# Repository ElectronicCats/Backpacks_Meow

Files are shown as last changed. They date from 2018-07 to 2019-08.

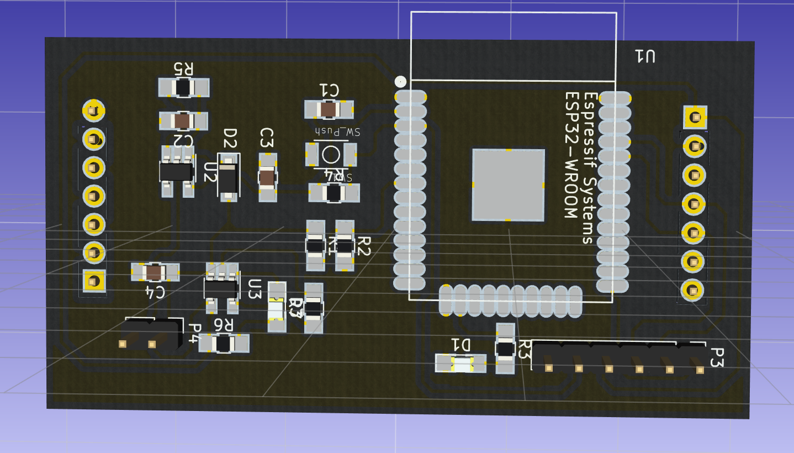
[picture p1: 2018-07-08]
BLE_WIFI_HID/BLE_WIFI_HID.png

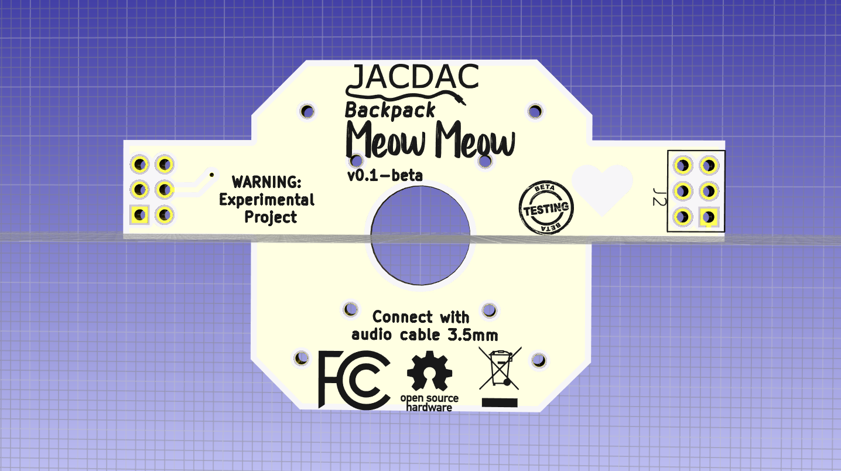
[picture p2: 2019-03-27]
jacdac/beta-v0.1_back.png

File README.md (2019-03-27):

# Backpacks Meow Meow

> WARNING: The Backpacks for Meow Meow are very much still under development and subject to change. If you would like to contribute features and ideas, please send pullrequest to this github repository or file an issue.

## Backpacks

### JACDAC

The JACDAC Connect system uses the JACDAC (Joint Asynchronous Communications) protocol, a single cable transmission protocol for the plug and play of accessories for microcontrollers.

We have adapted this technology to unlock the following benefits:

- No welding between JACDAC breakouts
- Connectors with 3.5mm audio plug to avoid connection errors.
- Ability to create a chain in series where you can connect multiple devices.

More [info about JACDAC](https://jacdac.org/)

### BLE HID
Add wireless connection functionality to your Meow Meow thanks to bluetooth 4.0

## LICENSE

Hardware released under an CERN Open Hardware Licence v1.2. See the LICENSE_HARDWARE file for more information.

Designed by Electronic Cats.

Electronic Cats is a registered trademark, please do not use if you sell these PCBs.

Electronic Cats invests time and resources providing this open source design, please support Electronic Cats and open-source hardware by purchasing products from Electronic Cats!

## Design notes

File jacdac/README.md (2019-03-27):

# Make JACDAC System with Meow Meow Backpack

> **Status Tutorial: Experimental**

This tutorial shows you how to build your own MakeCode JACDAC using an [Meow Meow](https://www.electroniccats.com) as the controller sensors device.

## Parts needed

Before you begin, you're going to need a few parts which are shown in the diagram below.

Also, here's a list of where you can buy the parts and a brief description of what each part does too.

* 2 x [Meow Meow](https://www.electroniccats.com) - This will run the code for the project you will be creating.
* 2 x [Meow Meow Backpack JACDAC](https://) - This will connect the Meow Meow to other Meow Meow, using our JACDAC protocol. 

# ALERT:

> **Always** only one device Meow Meow at a time must be connected to the computer.
> 
> Before starting, you must disconnect all the Meow Meows from the USB cable or any other external power supply

## Assembling your MakeCode

The diagram shown at the beginning is what we're going to build as we connect everything together.

### Step 1: Open Maker MakeCode
Open your browser and go to [https://maker.makecode.com/](https://maker.makecode.com/), open "New Project" and select the board Meow Meow, select in mode Javascript your editor code.

### Step 2: Connecting the 3.5mm Audio Jack Connector to the "Meow Meow Host" to the others "Meow Meow Peripheral"

Using a standard audio cable, connect your Meow Meow Host to the Meow Meows Peripheral, as shown in the picture below.

**[!Need an Meow Meow board connection image to go here!](#)**

It does not matter in which connector you place the cable and it is not necessary to make any other connection.

### Step 3: Load an example that uses JACDAC onto the Meow Meow Host 

As mentioned earlier, we're going to be using the protocol called JACDAC to connect the Meow Meow with others Meow Meow to a controller.

Load this code from MakeCode onto your Meow Meow Host:

```typescript-ignore
jacdac.keyboardService.start()
```
 
For more information on the JACDAC protocol, check out this link: [https://jacdac.org/](https://jacdac.org/
)

### Step 4: Load controller code onto Meow Meow Peripheral that uses JACDAC

The Meow Meows Peripheral serves as our controllers for the Meow Meow Host. 

Load this code from MakeCode (beta) onto your Meow Meows Peripherals to use it as a keyboard:

```typescript-ignore
enum JacDacMessage {
    message1 = 49434,
    start = 56380
}
input.touchA0.onEvent(ButtonEvent.Down, function () {
    jacdac.keyboardClient.mediaKey(JDKeyboardMediaKey.Mute, JDKeyboardKeyEvent.Press)
})
input.touchA5.onEvent(ButtonEvent.Down, function () {
    jacdac.keyboardClient.key("a", JDKeyboardKeyEvent.Press)
})
input.touchA1.onEvent(ButtonEvent.Down, function () {
    jacdac.keyboardClient.mediaKey(JDKeyboardMediaKey.VolumeUp, JDKeyboardKeyEvent.Press)
})
input.touchA2.onEvent(ButtonEvent.Down, function () {
    jacdac.keyboardClient.mediaKey(JDKeyboardMediaKey.VolumeDown, JDKeyboardKeyEvent.Press)
})
input.touchA3.onEvent(ButtonEvent.Down, function () {
    jacdac.keyboardClient.key("b", JDKeyboardKeyEvent.Press)
})
input.touchA4.onEvent(ButtonEvent.Down, function () {
    jacdac.keyboardClient.key("b", JDKeyboardKeyEvent.Press)
})
```

### Step 5: Connect the Meow Meow Host to PC

> Remember **always** only one device Meow Meow at a time must be connected to the computer.

After everything is plugged in, turn on the Meow Meow Host and start playing!!

Enjoy!

## TODO

* Add pictures
* Add gifs of example game running

## Resources

### Developer

* [Makecode Maker (beta)](https://maker.makecode.com/beta)
* [JACDAC](https://jacdac.org/)
* [ElectronicCats](https://www.electroniccats.com)

### Components

* [Meow Meow](https://www.electroniccats.com)
* [Meow Meow Backpack JACDAC](https://www.adafruit.com/product/2791/)

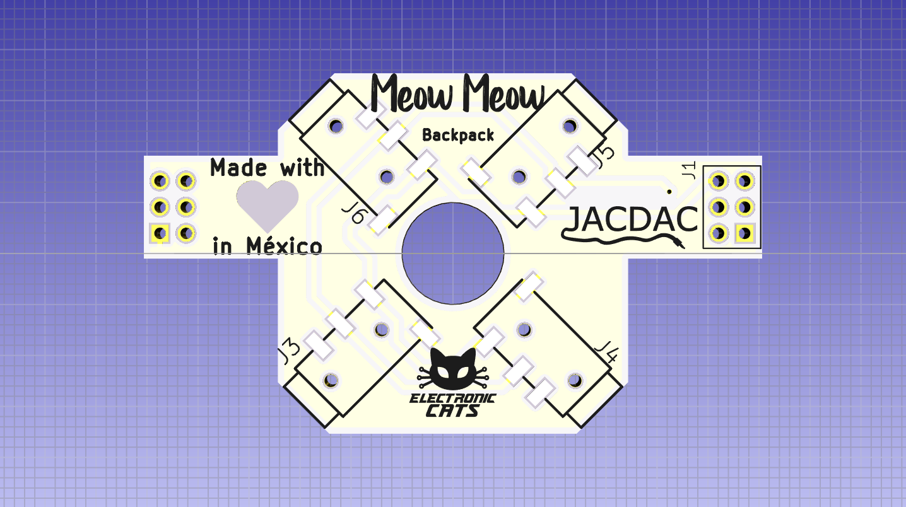
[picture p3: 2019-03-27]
jacdac/beta-v0.1_front.png

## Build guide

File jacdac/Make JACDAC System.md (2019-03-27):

# Make JACDAC System

This tutorial shows you how to build your own MakeCode JACDAC using an [Meow Meow](https://www.electroniccats.com), and the [Bast](https://www.electroniccats.com) as the controller sensors device.

## Parts needed

Before you begin, you're going to need a few parts which are shown in the diagram below.

Also, here's a list of where you can buy the parts and a brief description of what each part does too.

* [Meow Meow](https://www.electroniccats.com) - This will run the code for the game you will be creating.
* [Bast](https://www.electroniccats.com) - This act as your sensor device.
* [3.5mm Stereo Audio Jack Connector](https://www.adafruit.com/product/2791/) - This will connect the Meow Meow to the Bast, using our JACDAC protocol. 

## Assembling your MakeCode

The diagram shown at the beginning is what we're going to build as we connect everything together.

### Step 1: Connecting the 3.5mm Audio Jack Connector to the Meow Meow #step-1

Follow the diagram above to connect the audio jack.  For reference, this small chart shows the mapping for a typical 3.5mm Stero audio jack connector/pins to the protocol we will be using later (JACDAC). 

| 3.5mm Connector | JACDAC Protocol|
| --- | --- |
| Tip (or Left) | Connect to power source (if you want to draw power) |
| Ring (or Right) | Connect to data or tx line |
| Sleeve (or Ground) | Connect to a ground pin|
<br/>

Connecting the audio jack simply requires connecting the ring pin of the audio connector to the **TX** pin of the Meow Meow and connecting the sleeve pin of the audio connector to the ground (**G**) pin of the Meow Meow.

### Step 2: Connecting the 3.5mm Audio Jack Connector to the Cat hairs ball

Follow the diagram above for reference. Similar to [Step 1](#step-1), connect the ring pin of the audio connector to the **TX** pin of the cat hairs ball and connecting the sleeve pin of the audio connector to the **GND** pin of the Bast.

### Step 3: Load an example that uses JACDAC onto the Meow Meow

As mentioned earlier, we're going to be using the protocol called JACDAC to connect the Meow Meow with the screen to a controller. We do this because the Meow Meow contains the logic for the game, except it doesn't have enough pins for us to map buttons to an arcade controller. JACDAC lets us hook up different devices using audio connectors/cables, which is why we'll use the Basr as our controller.

Load this code from MakeCode onto your Meoe Meow:

```typescript-ignore
// code here or maybe a link???
// ...
```

>-- OR --
  
Load this code onto your Meow Meow:

```typescript-ignore
// code here or maybe a link???
// ...
```
 
For more information on the JACDAC protocol, check out this link: https://jacdac.org/

### Step 4: Load controller code onto the cat hairs ball that uses JACDAC

The cat hairs ball serves as our controller for the games we've already loaded onto the Meow Meow. 

Load this code from MakeCode (beta) onto your Bast to use it as a controller:

```typescript-ignore
// Bast controller code here or maybe a link???
// ...
```

### Step 5: Connect the the Meow Meow to the Bast

Using a standard audio cable, connect your Meow Meow to the Bast, as shown in the picture below.

**[!Need an Meow Meow board connection image to go here!](#)**

### Step 6: Enjoy!

After everything is plugged in, turn on both the Meow Meow and the Bast and start playing!!

## Todos

* Add Meow Meow code example link with JacDac
* Add Bast code example link with JacDac
* Add pictures
* Add gifs of example game running

## Resources

### Developer

* [Makecode Arcade (beta)](https://arcade.makecode.com/beta)
* [Makecode Maker (beta)](https://maker.makecode.com/beta)
* [JACDAC](https://jacdac.org/)
* [Adafruit](https://www.adafruit.com)

### Components

* [Meow Meow](https://www.electroniccats.com)
* [Bast](https://www.electroniccats.com)
* [3.5mm Stereo Audio Jack Connector](https://www.adafruit.com/product/2791/)

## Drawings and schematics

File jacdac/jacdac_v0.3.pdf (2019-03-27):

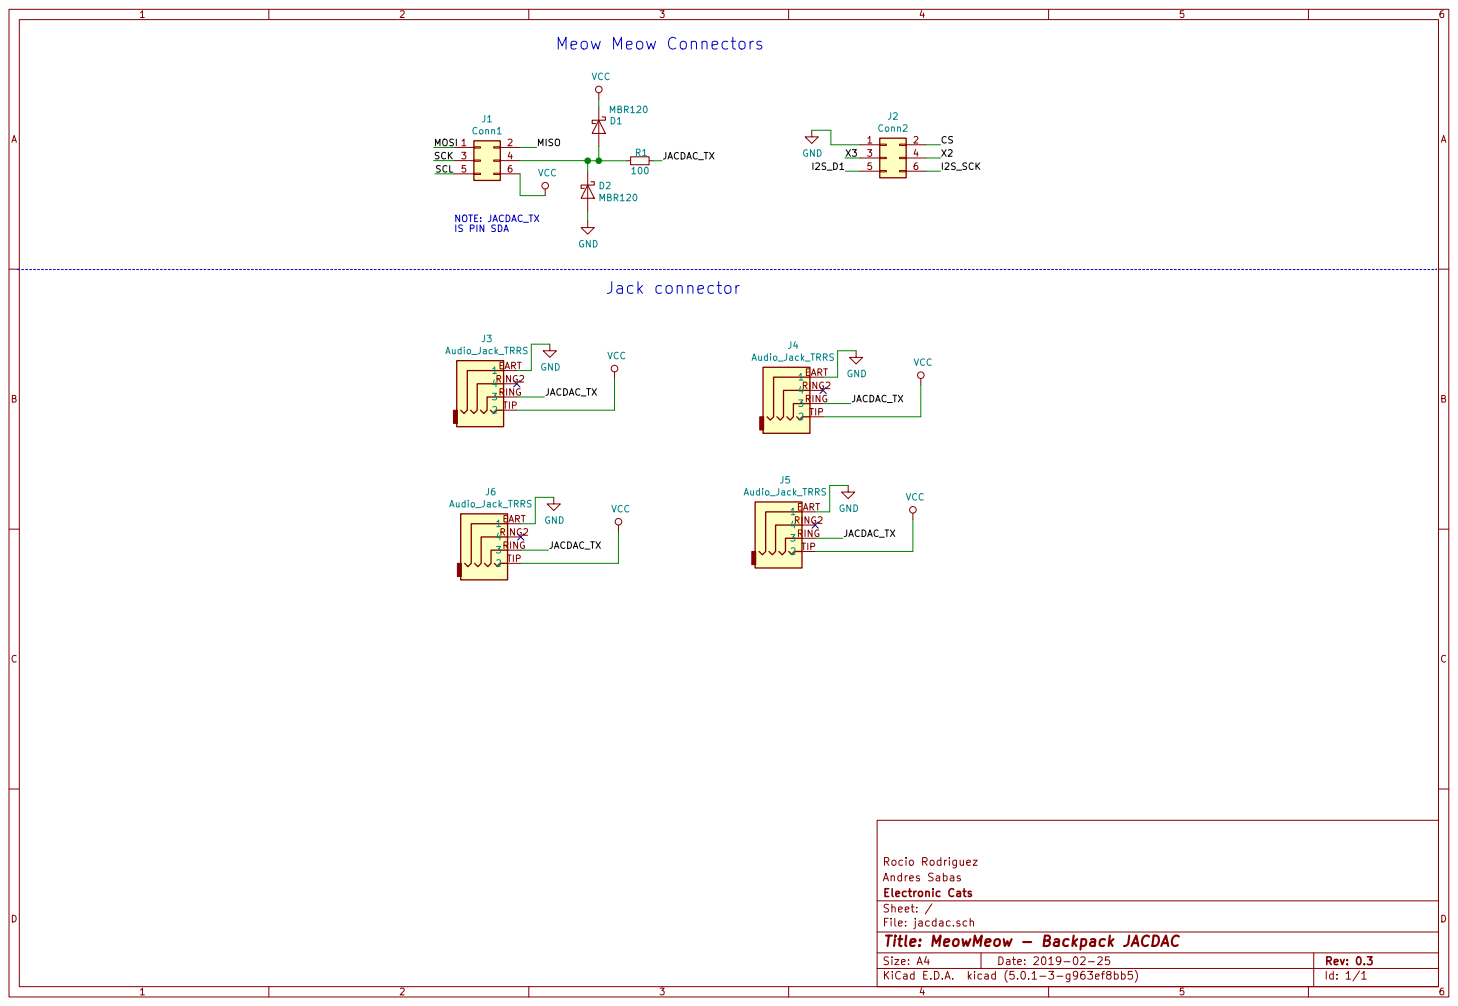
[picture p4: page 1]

File: jacdac.sch Sheet: / Electronic Cats Andres Sabas Rocio Rodriguez

Id: 1/1 Title: MeowMeow - Backpack JACDAC

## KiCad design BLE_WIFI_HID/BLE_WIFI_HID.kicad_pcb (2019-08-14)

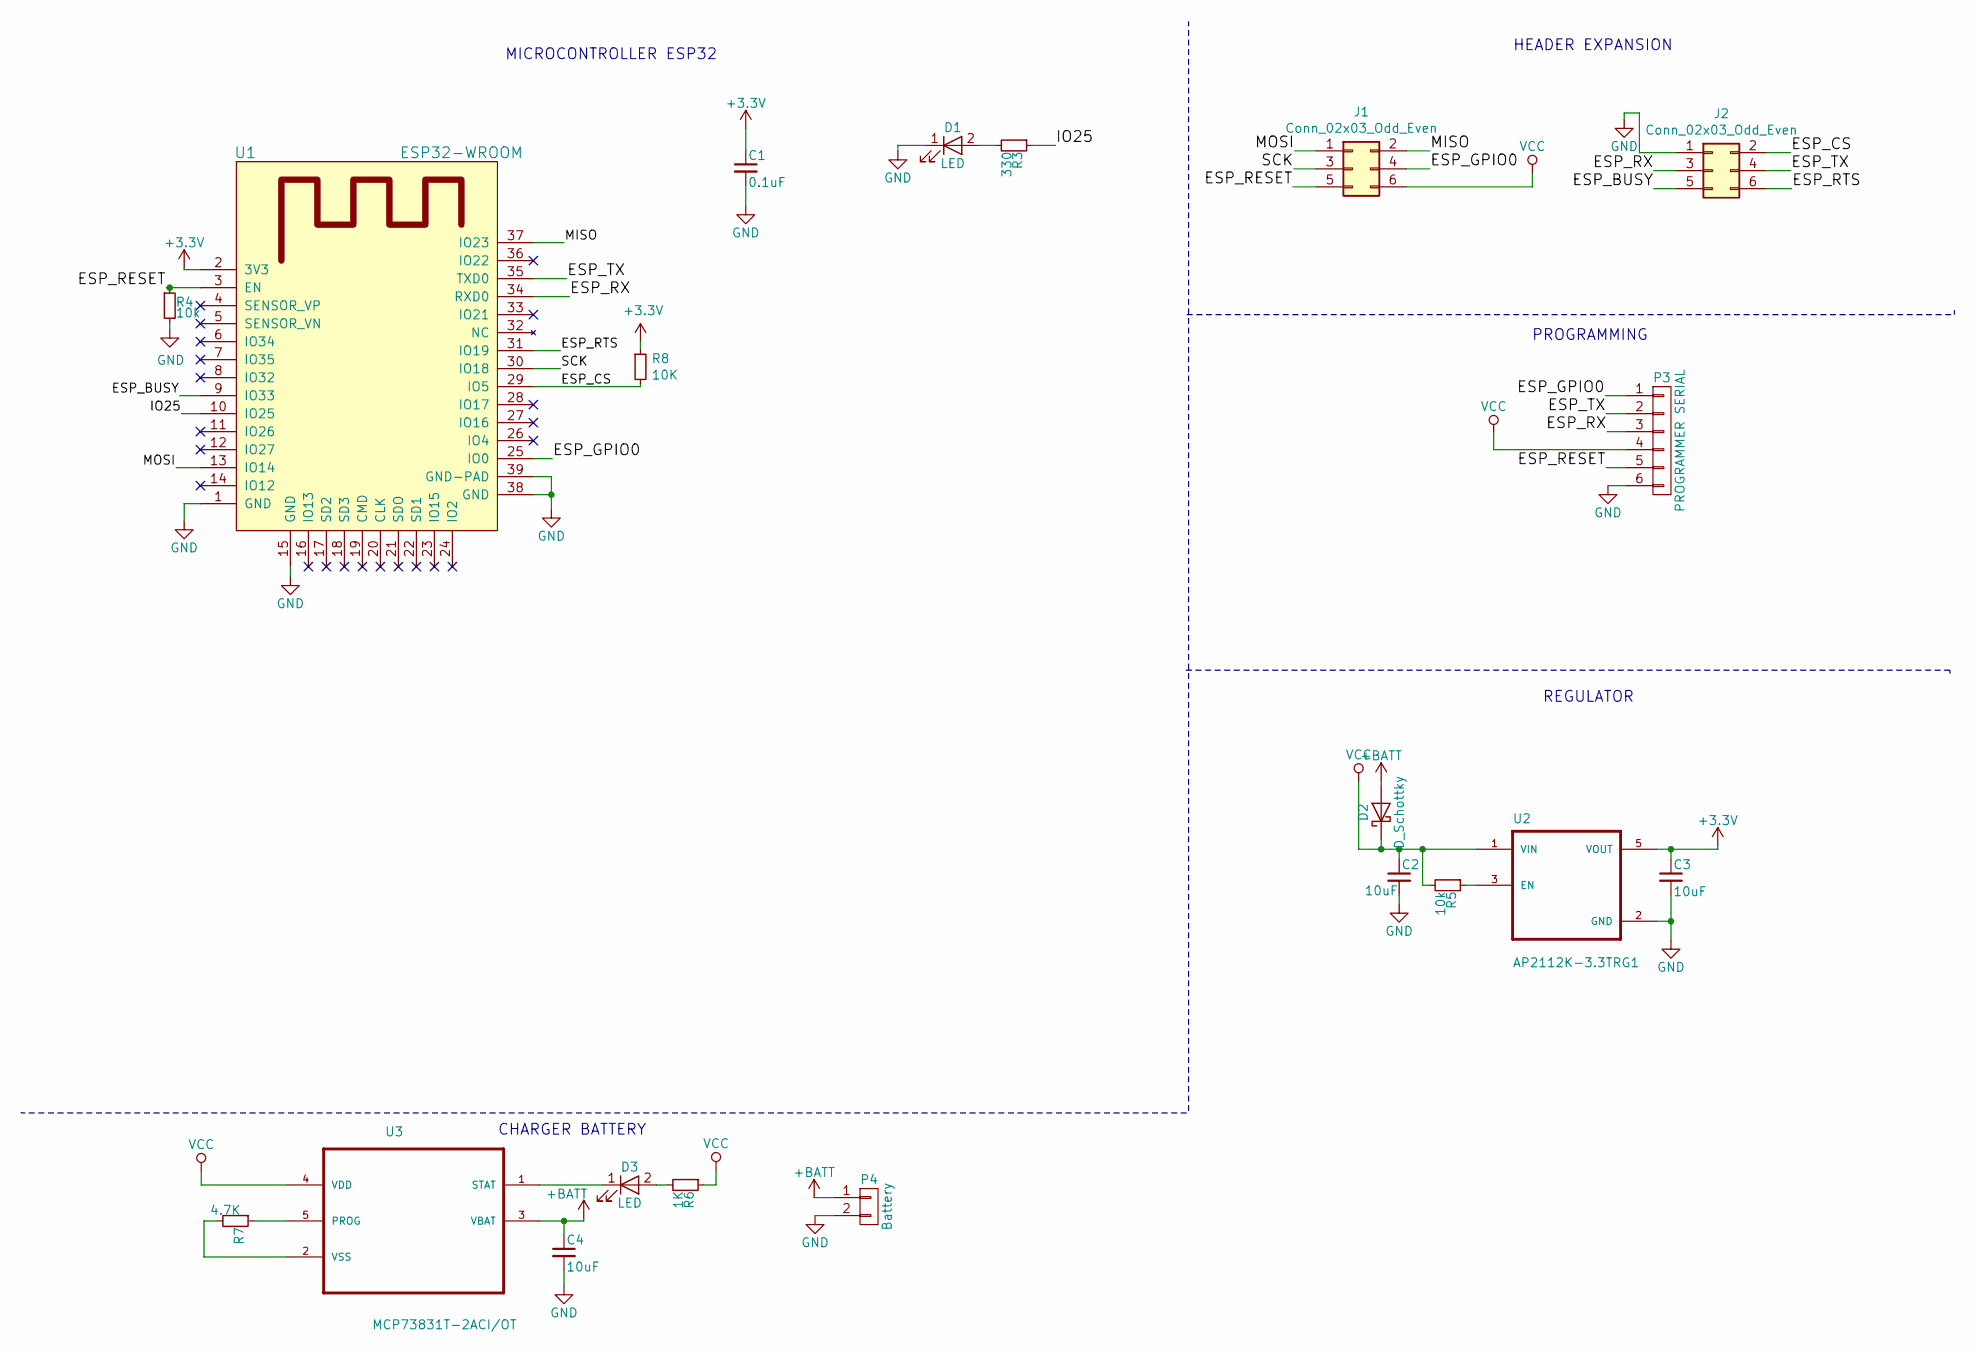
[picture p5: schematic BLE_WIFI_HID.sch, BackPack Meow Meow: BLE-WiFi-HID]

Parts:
C1: 0.1uF; C_0805_HandSoldering
C2, C3, C4: 10uF; C_0805_HandSoldering
D1, D3: LED; LED_0805_HandSoldering
D2: D_Schottky; D_SOD-123F
J1, J2: Conn_02x03_Odd_Even; 62000621121
P3: PROGRAMMER SERIAL; Pin_Header_Straight_1x06_Pitch2.54mm
P4: Battery; Pin_Header_Straight_1x02_Pitch2.54mm
R3: 330; R_0805_HandSoldering
R4, R5: 10k; R_0805_HandSoldering
R6: 1K; R_0805_HandSoldering
R7: 4.7K; R_0805_HandSoldering
R8: 10K; R_0805_HandSoldering
U1: ESP32-WROOM
U2: AP2112K-3.3TRG1; SOT-23-5_HandSoldering
U3: MCP73831T-2ACI/OT; SOT-23-5_HandSoldering

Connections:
+3V3: C1.1, C3.1, R8.1, U1.2 (3V3), U2.5 (VOUT)
+BATT: C4.1, D2.2 (A), P4.1, U3.3 (VBAT); also elsewhere on the board
/ESP_BUSY: J2.5, U1.9 (IO33)
/ESP_CS: J2.2, R8.2, U1.29 (IO5)
/ESP_GPIO0: J1.4, P3.1, U1.25 (IO0)
/ESP_RESET: J1.5, P3.5, R4.1, U1.3 (EN)
/ESP_RTS: J2.6, U1.31 (IO19)
/ESP_RX: J2.3, P3.3, U1.34 (RXD0)
/ESP_TX: J2.4, P3.2, U1.35 (TXD0)
/IO25: R3.1, U1.10 (IO25)
/MISO: J1.2, U1.37 (IO23)
/MOSI: J1.1, U1.13 (IO14)
/SCK: J1.3, U1.30 (IO18)
GND: C1.2, C2.2, C3.2, C4.2, D1.1 (K), J2.1, P3.6, P4.2, R4.2, U1.1 (GND), U1.15 (GND), U1.38 (GND), U1.39 (GND-PAD), U2.2 (GND); also elsewhere on the board
unnamed: D1.2 (A), R3.2
unnamed: D3.1 (K), U3.1 (STAT)
unnamed: D3.2 (A), R6.2
unnamed: R5.1, U2.3 (EN)
unnamed: R7.1, U3.5 (PROG)
unnamed: R7.2, U3.2 (VSS)
VCC: C2.1, D2.1 (K), J1.6, P3.4, R5.2, R6.1, U2.1 (VIN), U3.4 (VDD)

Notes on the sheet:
MICROCONTROLLER ESP32
HEADER EXPANSION
PROGRAMMING
CHARGER BATTERY
REGULATOR

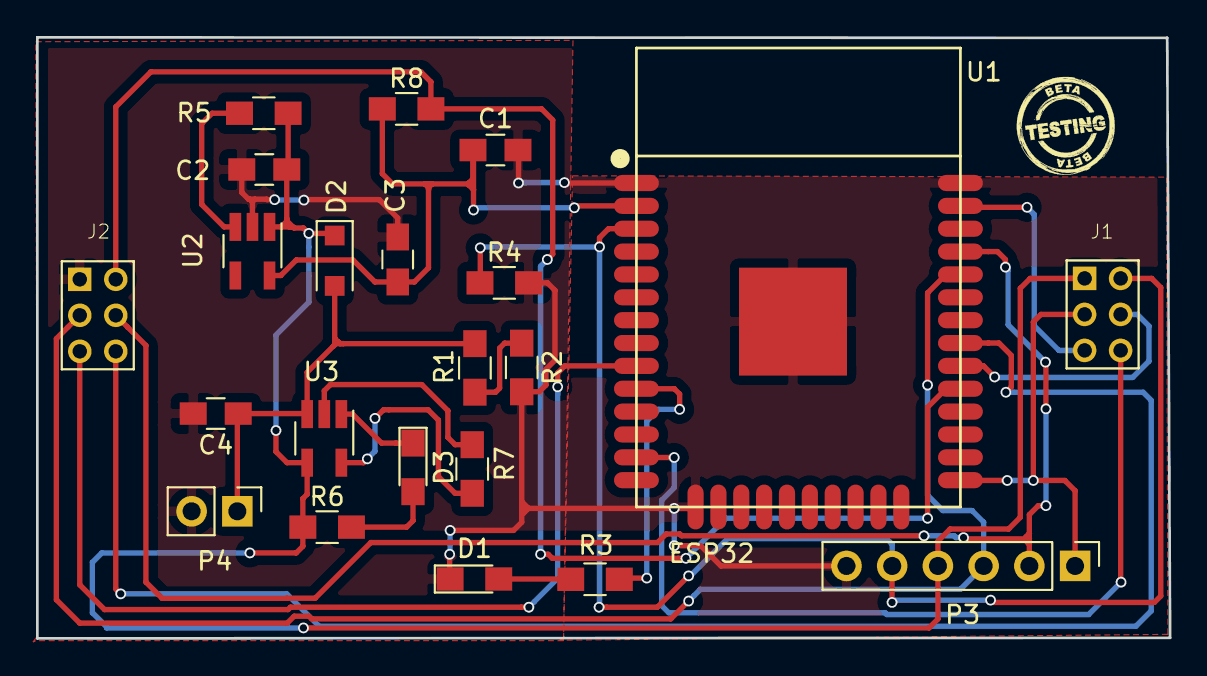
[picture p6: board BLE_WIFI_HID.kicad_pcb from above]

Board: 2 copper layers, 62.9 x 33.4 mm, 22 parts (0 on the bottom side), 22 nets.

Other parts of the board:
R1, R2: 100k; R_0805_HandSoldering

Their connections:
+BATT: R1.1; also elsewhere on the board
/AN35_BAT: R1.2, R2.1
GND: R2.2; also elsewhere on the board

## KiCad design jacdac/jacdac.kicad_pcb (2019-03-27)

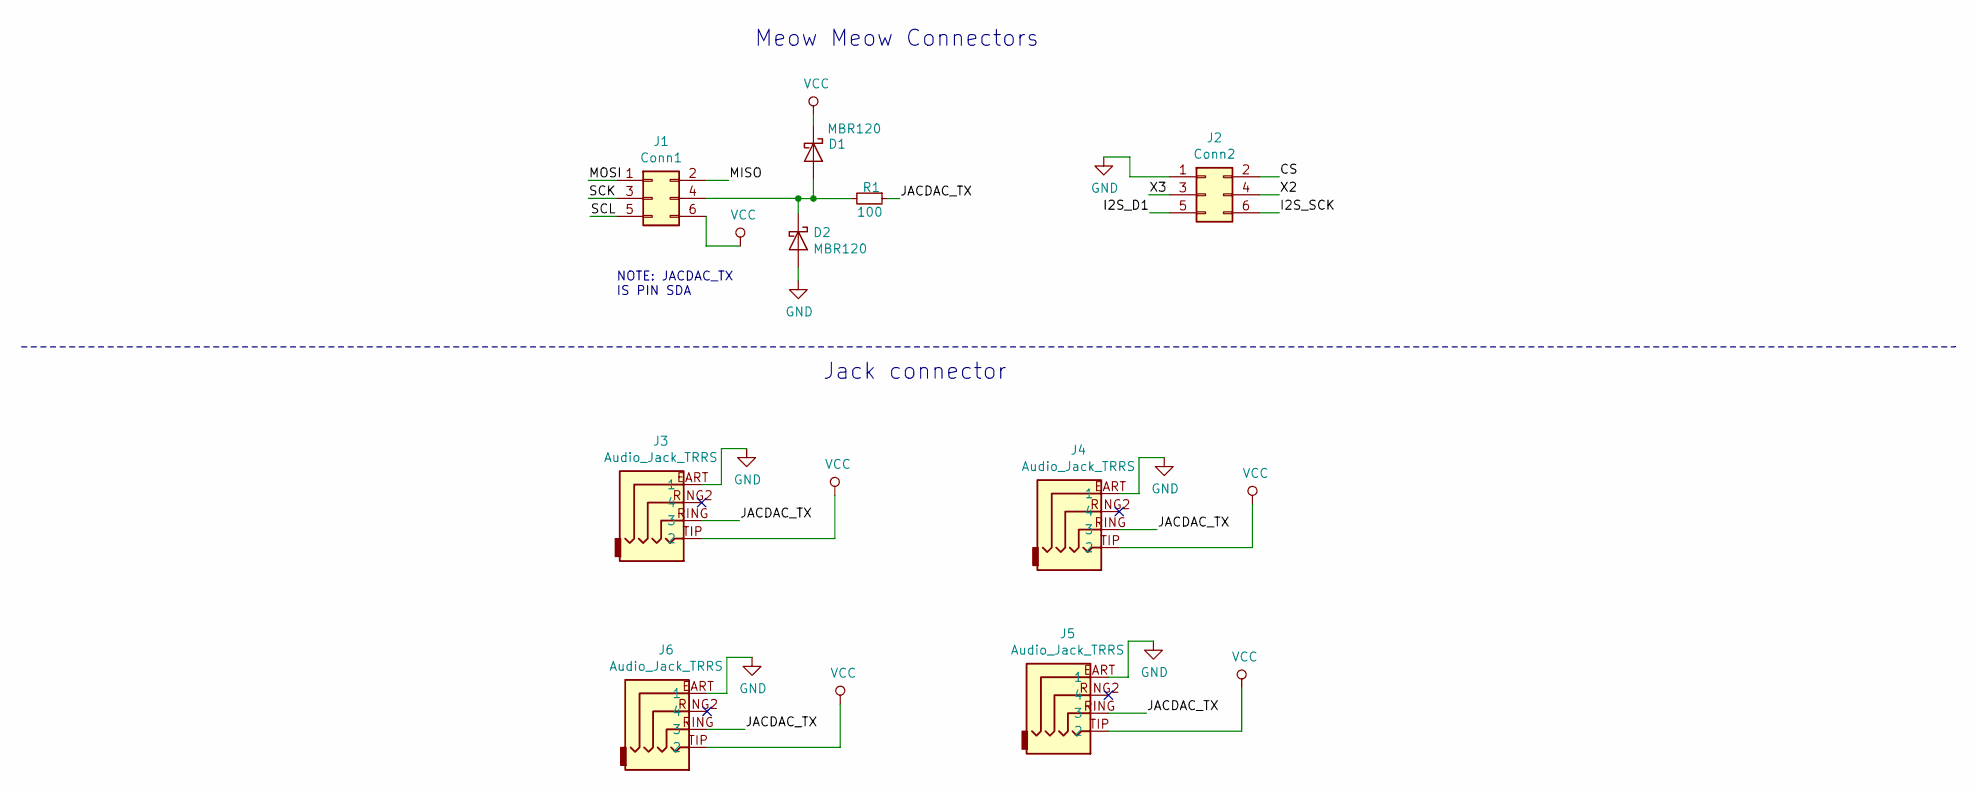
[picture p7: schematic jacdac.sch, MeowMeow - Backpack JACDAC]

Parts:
D1, D2: MBR120; D_SOD-123F
J1: Conn1; 61300621121
J2: Conn2; 61300621121
J3, J4, J5, J6: Audio_Jack_TRRS; AUDIO-JACK-TRRS-SMD
R1: 100; R_0805_HandSoldering

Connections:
/CS: J2.2
/I2S_D1: J2.5
/I2S_SCK: J2.6
/JACDAC_TX: J3.RING (3), J4.RING (3), J5.RING (3), J6.RING (3), R1.1
/MISO: J1.2
/MOSI: J1.1
/SCK: J1.3
/SCL: J1.5
/X2: J2.4
/X3: J2.3
GND: D2.2 (A), J2.1, J3.EART (1), J4.EART (1), J5.EART (1), J6.EART (1)
unnamed: D1.2 (A), D2.1 (K), J1.4, R1.2
VCC: D1.1 (K), J1.6, J3.TIP (2), J4.TIP (2), J5.TIP (2), J6.TIP (2)

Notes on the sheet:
Meow Meow Connectors
NOTE: JACDAC_TX IS PIN SDA
Jack connector

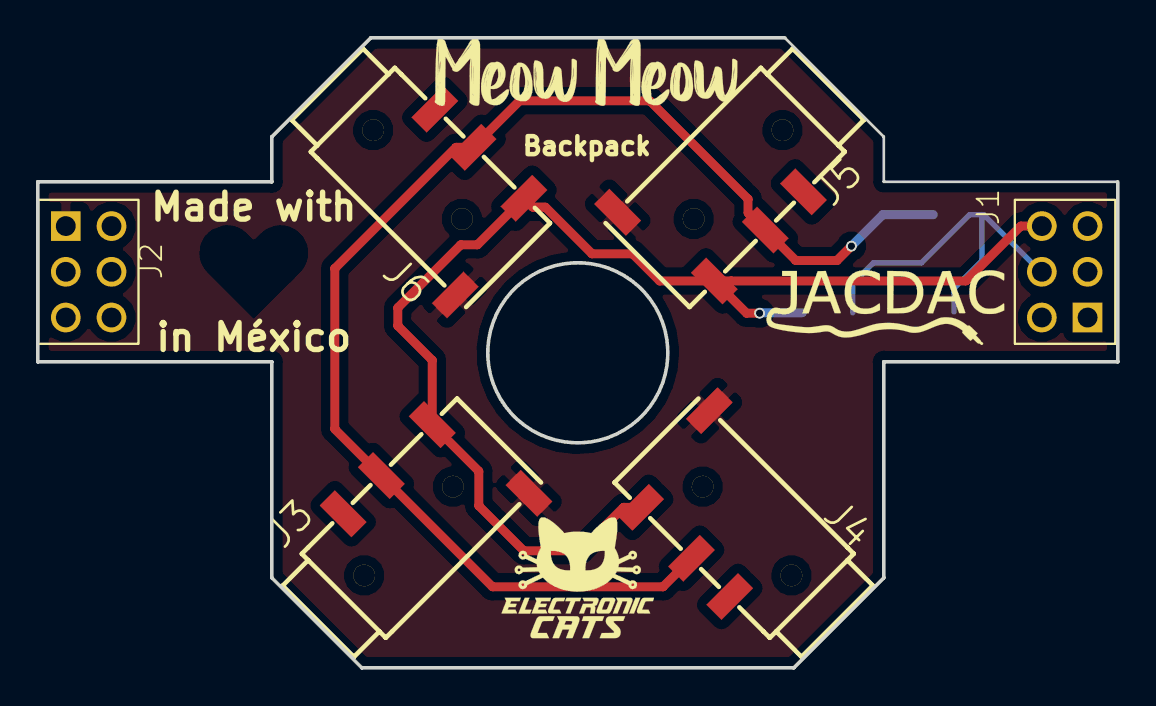
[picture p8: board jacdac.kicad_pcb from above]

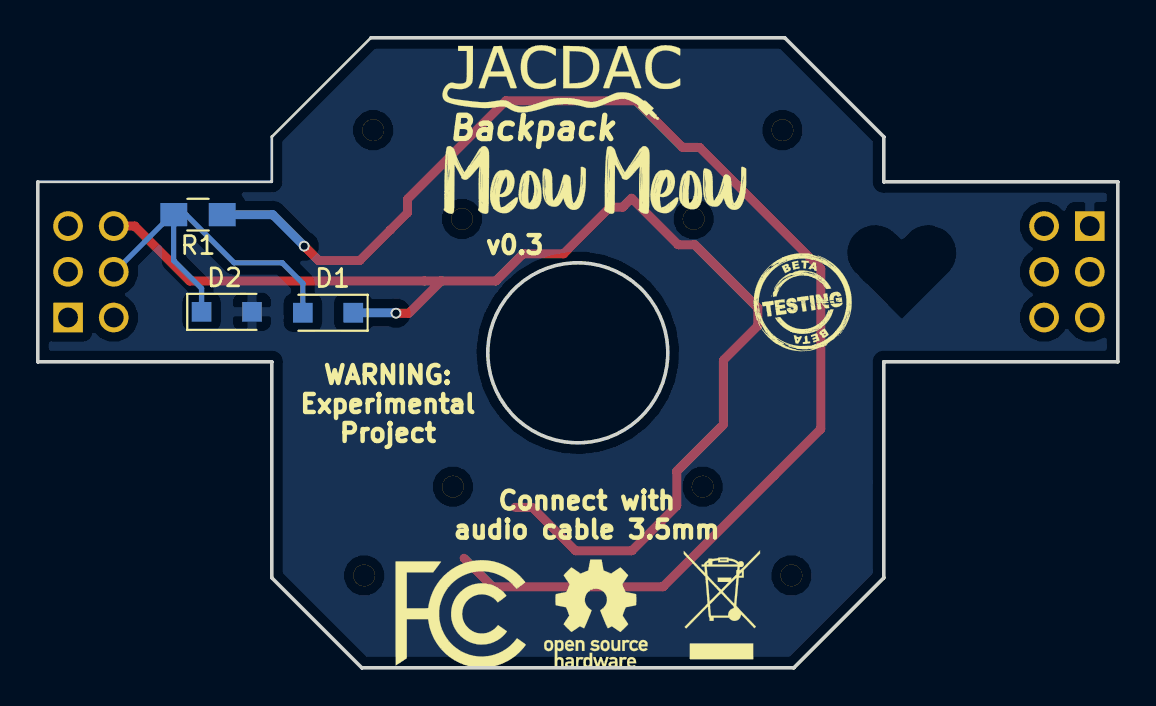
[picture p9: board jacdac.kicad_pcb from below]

Board: 2 copper layers, 60.0 x 35.0 mm, 11 parts (4 on the bottom side), 4 nets.

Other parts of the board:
svg2mod, svg2mod#2: G***; heart_trans

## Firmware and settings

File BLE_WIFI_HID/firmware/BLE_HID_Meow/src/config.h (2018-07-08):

 
#ifndef _CONFIG_H_
#define _CONFIG_H_

#define MODULE_ID "ESP32miniBT_v0.1"
#define GATTS_TAG "FLIPMOUSE"
#define MAX_BT_DEVICENAME_LENGTH 40

// serial port of monitor and for debugging
#define CONSOLE_UART_NUM UART_NUM_0

// serial port for connection to other controllers
#define EX_UART_NUM UART_NUM_2
#define EX_SERIAL_TXPIN      (GPIO_NUM_17)
#define EX_SERIAL_RXPIN      (GPIO_NUM_16)

// indicator LED
#define INDICATOR_LED_PIN    (GPIO_NUM_5)

typedef struct joystick_data {
    uint16_t X;
    uint16_t Y;
    uint16_t Z;
    uint16_t Z_rotate;
    uint16_t slider_left;
    uint16_t slider_right;
    uint16_t buttons1;
    uint16_t buttons2;
    int16_t hat;
} joystick_data_t;

typedef struct config_data {
    char bt_device_name[MAX_BT_DEVICENAME_LENGTH];
    uint8_t locale;
} config_data_t;


#endif

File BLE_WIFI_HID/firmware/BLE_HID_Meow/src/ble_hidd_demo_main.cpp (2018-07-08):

/*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
 * Copyright 2017 Benjamin Aigner <beni@asterics-foundation.org>
 */


#include <stdio.h>
#include <stdlib.h>
#include <string.h>
#include "freertos/FreeRTOS.h"
#include "freertos/task.h"
#include "freertos/event_groups.h"
#include "esp_system.h"
#include "esp_wifi.h"
#include "esp_event_loop.h"
#include "esp_log.h"
#include "nvs_flash.h"
#include "esp_bt.h"
#include "driver/gpio.h"

#include "config.h"
#include "HID_kbdmousejoystick.h"

#include "esp_gap_ble_api.h"
//#include "esp_hidd_prf_api.h"
/*#include "esp_bt_defs.h"
#include "esp_gatts_api.h"
#include "esp_gatt_defs.h"
#include "esp_bt_main.h"
#include "esp_bt_device.h"*/
#include "driver/gpio.h"
#include "driver/uart.h"
//#include "hid_dev.h"
#include "keyboard.h"

/** demo mouse speed */
#define MOUSE_SPEED 30
#define MAX_CMDLEN  100

#define EXT_UART_TAG "EXT_UART"
#define CONSOLE_UART_TAG "CONSOLE_UART"


static uint8_t keycode_modifier=0;
static uint8_t keycode_deadkey_first=0;
//static joystick_data_t joystick;//currently unused, no joystick implemented
static config_data_t config;
// joystick_command_t joystickCmd;


void update_config()
{
    nvs_handle my_handle;
    esp_err_t err = nvs_open("config_c", NVS_READWRITE, &my_handle);
    if(err != ESP_OK) ESP_LOGE("MAIN","error opening NVS");
    err = nvs_set_str(my_handle, "btname", config.bt_device_name);
    if(err != ESP_OK) ESP_LOGE("MAIN","error saving NVS - bt name");
    err = nvs_set_u8(my_handle, "locale", config.locale);
    if(err != ESP_OK) ESP_LOGE("MAIN","error saving NVS - locale");
    printf("Committing updates in NVS ... ");
    err = nvs_commit(my_handle);
    printf((err != ESP_OK) ? "Failed!\n" : "Done\n");
    nvs_close(my_handle);
}


void sendKeyCode(uint8_t c, keyboard_action type) {
	keyboard_command_t keyboardCmd;
	keyboardCmd.type = type;
	keyboardCmd.keycode = c + ((uint16_t)keycode_modifier << 8);
	xQueueSend(keyboard_q,(void *)&keyboardCmd, (TickType_t) 0);
}

void sendKey(uint8_t c, keyboard_action type) {
    uint8_t keycode;
	keycode = parse_for_keycode(c,config.locale,&keycode_modifier,&keycode_deadkey_first); //send current byte to parser
	if(keycode == 0) 
	{
		ESP_LOGI(EXT_UART_TAG,"keycode is 0 for 0x%X, skipping to next byte",c);
		return; //if no keycode is found,skip to next byte (might be a 16bit UTF8)
	}
	ESP_LOGI(EXT_UART_TAG,"keycode: %d, modifier: %d, deadkey: %d",keycode,keycode_modifier,keycode_deadkey_first);
	//TODO: do deadkey sequence...
		//if a keycode is found, add to keycodes for HID
	sendKeyCode(keycode, type);
}





#define CMDSTATE_IDLE 0
#define CMDSTATE_GET_RAW 1
#define CMDSTATE_GET_ASCII 2

struct cmdBuf {
    int state;
	int expectedBytes;
	int bufferLength;
	uint8_t buf[MAX_CMDLEN];
} ;

uint8_t uppercase(uint8_t c) 
{
	if ((c>='a') && (c<='z')) return (c-'a'+'A');
	return(c);
}

int get_int(const char * input, int index, int * value) 
{
  int sign=1, result=0, valid=0;

  while (input[index]==' ') index++;   // skip leading spaces
  if (input[index]=='-') { sign=-1; index++;}
  while ((input[index]>='0') && (input[index]<='9'))
  {
	  result= result*10+input[index]-'0';
	  valid=1;
	  index++;
  }
  while (input[index]==' ') index++;  // skip trailing spaces
  if (input[index]==',') index++;     // or a comma
  
  if (valid) { *value = result*sign; return (index);}
  return(0);  
}


void processCommand(struct cmdBuf *cmdBuffer)
{
    //commands:
    // $ID
    // $PMx (0 or 1)
    // $GP
    // $DPx (number of paired device, starting with 0)
    // $KW (+layouts)
    // $KD/KU
    // $KR
    // $KL
    // $M
    // $KC
    
    // TBD:
    // $KK (if necessary)
    // joystick (everything)
    
    if(cmdBuffer->bufferLength < 2) return;
    //easier this way than typecast in each str* function
    const char *input = (const char *) cmdBuffer->buf;
    int len = cmdBuffer->bufferLength;
    uint8_t keycode;
    const char nl = '\n';
	esp_ble_bond_dev_t * btdevlist;
	int counter;


    
    /**++++ commands without parameters ++++*/
    //get module ID
    if(strcmp(input,"ID") == 0) 
    {
        uart_write_bytes(EX_UART_NUM, MODULE_ID, sizeof(MODULE_ID));
        ESP_LOGD(EXT_UART_TAG,"sending module id (ID)");
        return;
    }

    //get all BT pairings
    if(strcmp(input,"GP") == 0)
    {
        counter = esp_ble_get_bond_device_num();
        char hexnum[5];
        
        if(counter > 0)
        {
            btdevlist = (esp_ble_bond_dev_t *) malloc(sizeof(esp_ble_bond_dev_t)*counter);
            if(btdevlist != NULL)
            {
                if(esp_ble_get_bond_device_list(&counter,btdevlist) == ESP_OK)
                {
                    ESP_LOGI(EXT_UART_TAG,"bonded devices (starting with index 0):");
                    ESP_LOGI(EXT_UART_TAG,"---------------------------------------");
                    for(uint8_t i = 0; i<counter;i++)
                    {
                        //print on monitor & external uart
                        esp_log_buffer_hex(EXT_UART_TAG, btdevlist[i].bd_addr, sizeof(esp_bd_addr_t));
                        for (int t=0; t<sizeof(esp_bd_addr_t);t++) {
								sprintf(hexnum,"%02X ",btdevlist[i].bd_addr[t]);
								uart_write_bytes(EX_UART_NUM, hexnum, 3);
						}
                        uart_write_bytes(EX_UART_NUM,&nl,sizeof(nl)); //newline
                    }
                    ESP_LOGI(EXT_UART_TAG,"---------------------------------------");
                } else ESP_LOGE(EXT_UART_TAG,"error getting device list");
            } else ESP_LOGE(EXT_UART_TAG,"error allocating memory for device list");
        } else ESP_LOGE(EXT_UART_TAG,"error getting bonded devices count or no devices bonded");
        return;
    }
    
    //joystick: update data (send a report)
    if(strcmp(input,"JU") == 0) 
    {
        //TBD: joystick
        ESP_LOGD(EXT_UART_TAG,"TBD! joystick: send report (JU)");
        return;
    }
    
    //keyboard: release all
    if(strcmp(input,"KR") == 0)
    {
		sendKeyCode(0, RELEASE_ALL);
        ESP_LOGD(EXT_UART_TAG,"keyboard: release all (KR)");
        return;
    }
    
    /**++++ commands with parameters ++++*/    
    switch(input[0])
    {
        case 'K': //keyboard
        {
			int param=0;
			if ((input[1] == 'U') || (input[1] == 'D') || (input[1] == 'L'))
			{
				if (!get_int(input,2,&param)) {
					ESP_LOGE(EXT_UART_TAG,"Keyboad command parameter needs integer format");
					break;
				}
			}

            //key up
            if(input[1] == 'U')
            {
                sendKeyCode(param, RELEASE);
                return;
            }
            //key down
            if(input[1] == 'D') 
            {
                sendKeyCode(param, PRESS);
                return;
            }
            //keyboard, set locale
            if(input[1] == 'L') 
            { 
				if(param < LAYOUT_MAX)   {
					config.locale = param;
					update_config();
				} else ESP_LOGE(EXT_UART_TAG,"Locale number out of range");
                return;
            }
            
            //keyboard, write
            if(input[1] == 'W')
            {
                ESP_LOGI(EXT_UART_TAG,"sending keyboard write, len: %d (bytes, not characters!)",len-2);
                for(uint16_t i = 2; i<len; i++)
                {
                    if(input[i] == '\0') 
                    {
                        ESP_LOGI(EXT_UART_TAG,"terminated string, ending KW");
                        break;
                    }
                    sendKey(input[i],PRESS_RELEASE);
                }
                return;
            }
            
            //keyboard, get keycode for unicode bytes
            if(input[1] == 'C' && len == 4) 
            {
                keycode = get_keycode(input[2],config.locale,&keycode_modifier,&keycode_deadkey_first);
                //if the first byte is not sufficient, try with second byte.
                if(keycode == 0) 
                { 
                    keycode = get_keycode(input[3],config.locale,&keycode_modifier,&keycode_deadkey_first);
                }
                //first the keycode + modifier are sent.
                //deadkey starting key is sent afterwards (0 if not necessary)
                uart_write_bytes(EX_UART_NUM, (char *)&keycode, sizeof(keycode));
                uart_write_bytes(EX_UART_NUM, (char *)&keycode_modifier, sizeof(keycode_modifier));
                uart_write_bytes(EX_UART_NUM, (char *)&keycode_deadkey_first, sizeof(keycode_deadkey_first));
                uart_write_bytes(EX_UART_NUM, &nl, sizeof(nl));
                return;
            }
            //keyboard, get unicode mapping between 2 locales
            if(input[1] == 'K' && len == 6) 
            { 
                //cpoint = get_cpoint((input[2] << 8) || input[3],input[4],input[5]);
                //uart_write_bytes(EX_UART_NUM, (char *)&cpoint, sizeof(cpoint));
                //uart_write_bytes(EX_UART_NUM, &nl, sizeof(nl));
                //TODO: is this necessary or useful anyway??
                return;
            }
            break;
		}
        case 'J': //joystick
            //joystick, set X,Y,Z (each 0-1023)
            if(input[1] == 'S' && len == 8) { }
            //joystick, set Z rotate, slider left, slider right (each 0-1023)
            if(input[1] == 'T' && len == 8) { }
            //joystick, set buttons (bitmap for button nr 1-16)
            if(input[1] == 'B' && len == 4) { }
            //joystick, set hat (0-360°)
            if(input[1] == 'H' && len == 4) { }
            //TBD: joystick
            ESP_LOGD(EXT_UART_TAG,"TBD! joystick");
            break;
        
        default: //test for management commands
            break;
    }

    // M <buttons> <X> <Y> <wheel>
    // create mouse activity
    if(input[0] == 'M')
    {
		int index=1, value;
		mouse_command_t mouseCmd;

		if ((index=get_int(input,index,&value))) mouseCmd.buttons = value; else return;
		if ((index=get_int(input,index,&value))) mouseCmd.x = value; else return;
		if ((index=get_int(input,index,&value))) mouseCmd.y = value; else return;
		if ((index=get_int(input,index,&value))) mouseCmd.wheel = value; else return;

        xQueueSend(mouse_q,(void *)&mouseCmd, (TickType_t) 0);
        ESP_LOGI(EXT_UART_TAG,"mouse command: %d,%d,%d,%d",mouseCmd.buttons,mouseCmd.x,mouseCmd.y,mouseCmd.wheel);
        return;
    }
    
    //DP: delete one pairing
    if(input[0] == 'D' && input[1] == 'P')
    {
		int index_to_remove;
		if (!(get_int(input,2,&index_to_remove))) { 
			ESP_LOGE(EXT_UART_TAG,"DP: invalid parameter, need integer");
			return;
		}
		
        counter = esp_ble_get_bond_device_num();
        if(counter == 0)
        {
            ESP_LOGE(EXT_UART_TAG,"error deleting device, no paired devices");
            return; 
        }
        
        if(index_to_remove >= counter)
        {
            ESP_LOGE(EXT_UART_TAG,"error deleting device, number out of range");
            return;
        }
        if(counter >= 0)
        {
            btdevlist = (esp_ble_bond_dev_t *) malloc(sizeof(esp_ble_bond_dev_t)*counter);
            if(btdevlist != NULL)
            {
                if(esp_ble_get_bond_device_list(&counter,btdevlist) == ESP_OK)
                {
                    esp_ble_remove_bond_device(btdevlist[index_to_remove].bd_addr);
                } else ESP_LOGE(EXT_UART_TAG,"error getting device list");
                free (btdevlist);
            } else ESP_LOGE(EXT_UART_TAG,"error allocating memory for device list");
        } else ESP_LOGE(EXT_UART_TAG,"error getting bonded devices count");
        ESP_LOGE(EXT_UART_TAG,"TBD: delete pairing");
        return;
    }

    //PM: enable/disable advertisting/pairing
    if(input[0] == 'P' && input[1] == 'M')
    {
		int param;
		if (!(get_int(input,2,&param))) { 
			ESP_LOGE(EXT_UART_TAG,"PM: invalid parameter, need integer");
			return;
		}
		
        if(param == 0)
        {
            HID_kbdmousejoystick_deactivatePairing();
            ESP_LOGI(EXT_UART_TAG,"PM: pairing deactivated");

        } else if(param == 1) 
        {
            HID_kbdmousejoystick_activatePairing();
            ESP_LOGI(EXT_UART_TAG,"PM: pairing activated");

        } else ESP_LOGE(EXT_UART_TAG,"PM: parameter error, either 0 or 1");
        return;
    }
    
    //set BT GATT advertising name
    if(strncmp(input,"NAME ", 5) == 0) 
    {
		if ((strlen(input)>6) && (strlen(input)-4<MAX_BT_DEVICENAME_LENGTH))
		{
			strcpy (config.bt_device_name, input+5);
			update_config();
			ESP_LOGI(EXT_UART_TAG,"NAME: new bt device name was stored");
		}
		else ESP_LOGI(EXT_UART_TAG,"NAME: given bt name is too long or too short");
		return;
    }
    
    ESP_LOGE(EXT_UART_TAG,"No command executed with: %s ; len= %d\n",input,len);
}



void uart_parse_command (uint8_t character, struct cmdBuf * cmdBuffer)
{
    static uint8_t keycode = 0;
    
    switch (cmdBuffer->state) {
		
		case CMDSTATE_IDLE:  
				if (character==0xfd) {
					cmdBuffer->bufferLength=0;
					cmdBuffer->expectedBytes=8;   // 8 bytes for raw report size
					cmdBuffer->state=CMDSTATE_GET_RAW;
				}
				else if (character == '$') {
					cmdBuffer->bufferLength=0;   // we will read an ASCII-command until CR or LF  
					cmdBuffer->state=CMDSTATE_GET_ASCII;
				}
				else sendKey(character, PRESS_RELEASE);         // treat whatever comes in as keyboard output
				break;
							
		case CMDSTATE_GET_RAW:
				cmdBuffer->buf[cmdBuffer->bufferLength]=character;
				//if ((cmdBuffer->bufferLength == 1) && (character==0x00))  // we have a keyboard report: increase by 2 bytes
				  // cmdBuffer->expectedBytes += 2;

				cmdBuffer->bufferLength++;
				cmdBuffer->expectedBytes--;
				if (!cmdBuffer->expectedBytes) {
					if (cmdBuffer->buf[1] == 0x00) {   // keyboard report				
						// TBD: synchonize with semaphore!	
						if(HID_kbdmousejoystick_rawKeyboard(cmdBuffer->buf,8) != ESP_OK)
						{
							ESP_LOGE(EXT_UART_TAG,"Error sending raw kbd");
						} else ESP_LOGI(EXT_UART_TAG,"Keyboard sent");
					} else if (cmdBuffer->buf[1] == 0x03) {  // mouse report
						// TBD: synchonize with semaphore!	
						if(HID_kbdmousejoystick_rawMouse(&(cmdBuffer->buf[2]),4) != ESP_OK)
						{
							ESP_LOGE(EXT_UART_TAG,"Error sending raw mouse");
						} else ESP_LOGI(EXT_UART_TAG,"Mouse sent");

					}
                    else ESP_LOGE(EXT_UART_TAG,"Unknown RAW HID packet");
                    cmdBuffer->state=CMDSTATE_IDLE;
				}
				break;
				
		case CMDSTATE_GET_ASCII:
				if (character=='$')  {   //  key '$' can be created by sending "$$" 
					sendKey('$', PRESS_RELEASE);
					cmdBuffer->state=CMDSTATE_IDLE;
				} else {   // collect a command string until CR or LF are received
					if ((character==0x0d) || (character==0x0a))  {
						cmdBuffer->buf[cmdBuffer->bufferLength]=0;
						ESP_LOGI(EXT_UART_TAG,"sending command to parser: %s",cmdBuffer->buf);

						processCommand(cmdBuffer);
						cmdBuffer->state=CMDSTATE_IDLE;
					} else {
						if (cmdBuffer->bufferLength < MAX_CMDLEN-1) 
						  cmdBuffer->buf[cmdBuffer->bufferLength++]=character;
					}
				}
				break;
		default: 
 			cmdBuffer->state=CMDSTATE_IDLE;
	}
} 
					


void uart_console(void *pvParameters)
{
    char character;
	mouse_command_t mouseCmd;
	keyboard_command_t keyboardCmd;
    
    //Install UART driver, and get the queue.
    uart_driver_install(CONSOLE_UART_NUM, UART_FIFO_LEN * 2, UART_FIFO_LEN * 2, 0, NULL, 0);

    ESP_LOGI("UART","console UART processing task started");
    
    while(1)
    {
        // read single byte
        uart_read_bytes(CONSOLE_UART_NUM, (uint8_t*) &character, 1, portMAX_DELAY);
		// uart_parse_command(character, &cmdBuffer);	      	

		if(HID_kbdmousejoystick_isConnected() == 0) {
			ESP_LOGI(CONSOLE_UART_TAG,"Not connected, ignoring '%c'", character);
		} else {
			//Do not send anything if queues are uninitialized
			if(mouse_q == NULL || keyboard_q == NULL || joystick_q == NULL)
			{
				ESP_LOGE(CONSOLE_UART_TAG,"queues not initialized");
				continue;
			}
			switch (character){
				case 'a':
					mouseCmd.x = -MOUSE_SPEED;
					mouseCmd.y = 0;
					mouseCmd.buttons = 0;
					mouseCmd.wheel = 0;
					xQueueSend(mouse_q,(void *)&mouseCmd, (TickType_t) 0);
					ESP_LOGI(CONSOLE_UART_TAG,"mouse: a");
					break;
				case 's':
					mouseCmd.x = 0;
					mouseCmd.y = MOUSE_SPEED;
					mouseCmd.buttons = 0;
					mouseCmd.wheel = 0;
					xQueueSend(mouse_q,(void *)&mouseCmd, (TickType_t) 0);
					ESP_LOGI(CONSOLE_UART_TAG,"mouse: s");
					break;
				case 'd':
					mouseCmd.x = MOUSE_SPEED;
					mouseCmd.y = 0;
					mouseCmd.buttons = 0;
					mouseCmd.wheel = 0;
					xQueueSend(mouse_q,(void *)&mouseCmd, (TickType_t) 0);
					ESP_LOGI(CONSOLE_UART_TAG,"mouse: d");
					break;
				case 'w':
					mouseCmd.x = 0;
					mouseCmd.y = -MOUSE_SPEED;
					mouseCmd.buttons = 0;
					mouseCmd.wheel = 0;
					xQueueSend(mouse_q,(void *)&mouseCmd, (TickType_t) 0);
					ESP_LOGI(CONSOLE_UART_TAG,"mouse: w");
					break;
				case 'l':
					mouseCmd.x = 0;
					mouseCmd.y = 0;
					mouseCmd.buttons = 1;
					mouseCmd.wheel = 0;
					xQueueSend(mouse_q,(void *)&mouseCmd, (TickType_t) 0);
					mouseCmd.x = 0;
					mouseCmd.y = 0;
					mouseCmd.buttons = 0;
					mouseCmd.wheel = 0;
					xQueueSend(mouse_q,(void *)&mouseCmd, (TickType_t) 0);
					ESP_LOGI(CONSOLE_UART_TAG,"mouse: l");
					break;
				case 'r':
					mouseCmd.x = 0;
					mouseCmd.y = 0;
					mouseCmd.buttons = 2;
					mouseCmd.wheel = 0;
					xQueueSend(mouse_q,(void *)&mouseCmd, (TickType_t) 0);
					mouseCmd.x = 0;
					mouseCmd.y = 0;
					mouseCmd.buttons = 0;
					mouseCmd.wheel = 0;
					xQueueSend(mouse_q,(void *)&mouseCmd, (TickType_t) 0);
					ESP_LOGI(CONSOLE_UART_TAG,"mouse: r");
					break;
				case 'q':
					ESP_LOGI(CONSOLE_UART_TAG,"received q: sending key y for test purposes");
					keyboardCmd.keycode = 28;
					keyboardCmd.type = PRESS_RELEASE;
					xQueueSend(keyboard_q,(void *)&keyboardCmd, (TickType_t) 0);
					break;
				default:
					ESP_LOGI(CONSOLE_UART_TAG,"received: %d",character);
					break;
			}
		}
    }
}


void uart_external(void *pvParameters)
{
    char character;
    struct cmdBuf cmdBuffer;
    
    
    //Install UART driver, and get the queue.
	esp_err_t ret = ESP_OK;
	const uart_config_t uart_config = {
		.baud_rate = 9600,
		.data_bits = UART_DATA_8_BITS,
		.parity = UART_PARITY_DISABLE,
		.stop_bits = UART_STOP_BITS_1,
		.flow_ctrl = UART_HW_FLOWCTRL_DISABLE
	};
	
	//update UART config
	ret = uart_param_config(EX_UART_NUM, &uart_config);
	if(ret != ESP_OK) 
	{
		ESP_LOGE(EXT_UART_TAG,"external UART param config failed"); 
	}
	
	//set IO pins
	ret = uart_set_pin(EX_UART_NUM, EX_SERIAL_TXPIN, EX_SERIAL_RXPIN, UART_PIN_NO_CHANGE, UART_PIN_NO_CHANGE);
	if(ret != ESP_OK)
	{
		ESP_LOGE(EXT_UART_TAG,"external UART set pin failed"); 
	}
    uart_driver_install(EX_UART_NUM, UART_FIFO_LEN * 2, UART_FIFO_LEN * 2, 0, NULL, 0);
    
    ESP_LOGI(EXT_UART_TAG,"external UART processing task started");
    cmdBuffer.state=CMDSTATE_IDLE;
    
    while(1)
    {
        // read single byte
        uart_read_bytes(EX_UART_NUM, (uint8_t*) &character, 1, portMAX_DELAY);
        uart_parse_command(character, &cmdBuffer);	      	
    }
}

void blink_task(void *pvParameter)
{
    // Initialize GPIO pins
    gpio_pad_select_gpio(INDICATOR_LED_PIN);
    gpio_set_direction(INDICATOR_LED_PIN, GPIO_MODE_OUTPUT);
    int blinkTime;
    
    while(1) {
		
		if (HID_kbdmousejoystick_isConnected()) 
			blinkTime=1000;
		else blinkTime=250;
		
		
        /* Blink off (output low) */
        gpio_set_level(INDICATOR_LED_PIN, 0);
        vTaskDelay(blinkTime / portTICK_PERIOD_MS);
        /* Blink on (output high) */
        gpio_set_level(INDICATOR_LED_PIN, 1);
        vTaskDelay(blinkTime / portTICK_PERIOD_MS);
    }
}

extern "C" void app_main()
{
    esp_err_t ret;

    // Initialize NVS.
    ret = nvs_flash_init();
    if (ret == ESP_ERR_NVS_NO_FREE_PAGES) {
        ESP_ERROR_CHECK(nvs_flash_erase());
        ret = nvs_flash_init();
    }
    ESP_ERROR_CHECK( ret );

    // Read config
    nvs_handle my_handle;
	ESP_LOGI("MAIN","loading configuration from NVS");
    ret = nvs_open("config_c", NVS_READWRITE, &my_handle);
    if(ret != ESP_OK) ESP_LOGE("MAIN","error opening NVS");
    size_t available_size = MAX_BT_DEVICENAME_LENGTH;
    strcpy(config.bt_device_name, GATTS_TAG);
    nvs_get_str (my_handle, "btname", config.bt_device_name, &available_size);
    if(ret != ESP_OK) 
    {
        ESP_LOGE("MAIN","error reading NVS - bt name, setting to default");
        strcpy(config.bt_device_name, GATTS_TAG);
    } else ESP_LOGI("MAIN","bt device name is: %s",config.bt_device_name);

    ret = nvs_get_u8(my_handle, "locale", &config.locale);
    if(ret != ESP_OK || config.locale >= LAYOUT_MAX) 
    {
        ESP_LOGE("MAIN","error reading NVS - locale, setting to US_INTERNATIONAL");
        config.locale = LAYOUT_US_INTERNATIONAL;
    } else ESP_LOGI("MAIN","locale code is : %d",config.locale);
    nvs_close(my_handle);

    // TBD: apply country code
    // load HID country code for locale before initialising HID
    // hidd_set_countrycode(get_hid_country_code(config.locale));


    //activate mouse & keyboard BT stack (joystick is not working yet)
    HID_kbdmousejoystick_init(1,1,0,0,config.bt_device_name);
    ESP_LOGI("HIDD","MAIN finished...");
    
    esp_log_level_set("*", ESP_LOG_INFO); 

  
    // now start the tasks for processing UART input and indicator LED  
 
    xTaskCreate(&uart_console,  "console", 4096, NULL, configMAX_PRIORITIES, NULL);
    xTaskCreate(&uart_external, "external", 4096, NULL, configMAX_PRIORITIES, NULL);
    xTaskCreate(&blink_task, "blink", 4096, NULL, configMAX_PRIORITIES, NULL);
    
}

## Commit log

2018-06-28 Miss one pin and clear
2018-06-29 clean and new position
    [BLE_WIFI_HID.kicad_pcb]
2018-06-29 change the connectors
    [BLE_WIFI_HID.kicad_pcb]
2018-07-02 Auto stash before merge of "master" and "origin/master"
    [BLE_WIFI_HID.kicad_pcb]
2018-07-08 Rename and update example
    [partitions_custom.csv]
2019-02-11 init backpack jacdac
    [jacdac.kicad_pcb, jacdac.sch]
2019-02-11 one connector 4 pines
2019-02-13 update schematic to audio TRRS
    [jacdac.sch]
2019-02-13 init PCB
    [jacdac.kicad_pcb]
2019-02-14 update PCB
    [jacdac.kicad_pcb]
2019-02-14 add logo jacdac
    [jacdac.kicad_pcb]
2019-02-14 fix pin number jack TRRS
    [jacdac.sch]
2019-02-19 new headers
    [jacdac.sch]
2019-02-19 mode star
    [jacdac.kicad_pcb]
2019-02-19 version for test
    [jacdac.kicad_pcb]
2019-02-21 Label experimental project
    experimental project!!!
    [jacdac.kicad_pcb]
2019-02-21 version beta testing
    [jacdac.kicad_pcb]
2019-02-25 add schematic pdf
2019-02-25 init v0.2 add diodes and resistor
    [jacdac.kicad_pcb, jacdac.sch]
2019-03-05 Fix GND inverted
    [jacdac.kicad_pcb]
2019-03-17 WIFININA new
    [BLE_WIFI_HID.sch]
2019-03-17 change headers expansion
    [BLE_WIFI_HID.sch]
2019-03-18 update to v0.3 pcb
    [BLE_WIFI_HID.kicad_pcb, BLE_WIFI_HID.sch]
2019-03-27 bump :D
    [jacdac.kicad_pcb, jacdac.sch]
2019-03-27 update reset resistor ESP32
    [BLE_WIFI_HID.kicad_pcb, BLE_WIFI_HID.sch]
2019-07-11 Inicio routeo
    [BLE_WIFI_HID.kicad_pcb]
2019-07-12 Acomodo conectores
    [BLE_WIFI_HID.kicad_pcb]
2019-07-15 batt and reset
    [BLE_WIFI_HID.kicad_pcb]
2019-07-15 Change Esp
    [BLE_WIFI_HID.kicad_pcb]
2019-07-15 Ground plane
    [BLE_WIFI_HID.kicad_pcb]
2019-07-17 Conn left
    [BLE_WIFI_HID.kicad_pcb]
2019-07-17 Conn rigth
    [BLE_WIFI_HID.kicad_pcb]
2019-08-13 Component number
    [BLE_WIFI_HID.kicad_pcb]
2019-08-14 Version beta BLE and WIFI NINA
    [BLE_WIFI_HID.kicad_pcb]

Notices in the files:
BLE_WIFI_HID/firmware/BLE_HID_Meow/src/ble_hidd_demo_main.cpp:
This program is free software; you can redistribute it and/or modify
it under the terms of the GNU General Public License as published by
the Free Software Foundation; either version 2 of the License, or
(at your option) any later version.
